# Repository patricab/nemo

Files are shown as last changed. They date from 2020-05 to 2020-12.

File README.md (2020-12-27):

# Nemo - Template board for Atmega328P Microcontroller

This is a template project for a sufrace mounted board, for use with the Atmega328P TQFP package.

What's included:
- Full KiCAD project
- Bill of Materials (BOM)
- Schematic PDF Export

# Full KiCAD project
I have included all project files for use with the open source CAD software KiCAD.
This includes the schematic file, component libraries, netlist and PCB-files

# Schematic PDF Export
Included is a PDF export of the schematic file:

Schematic

# Bill of Materials (BOM)
I have also added a full bill of materials (minus the header-pins), which are sourced from [LCSC](LCSC.com).

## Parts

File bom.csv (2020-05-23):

Reference | Value | Footprint | Datasheet | Price (USD) | LCSC Part #
J5 | Conn_02x03_Odd_Even | Connector_PinHeader_1.27mm:PinHeader_2x03_P1.27mm_Vertical | ~
C5 | 0.33uF | Capacitor_SMD:C_0603_1608Metric_Pad1.05x0.95mm_HandSolder | ~ | 0.015829 | C507077
C6, C2 | 0.1uF | Capacitor_SMD:C_0603_1608Metric_Pad1.05x0.95mm_HandSolder | ~ | 0.015126 | C282518
Y1 | 16MHz | Crystal:Crystal_SMD_3225-4Pin_3.2x2.5mm_HandSoldering | ~ | 0.504318 | C387370
C3 | 18pF | Capacitor_SMD:C_0603_1608Metric_Pad1.05x0.95mm_HandSolder | ~ | 0.0169 | C415402
C4 | 22pF | Capacitor_SMD:C_0603_1608Metric_Pad1.05x0.95mm_HandSolder | ~ | 0.003915 | C376775
C1 | 10uF | Capacitor_SMD:C_0603_1608Metric_Pad1.05x0.95mm_HandSolder | ~ | 0.053491 | C91606
D1 | 1N4001 | Diode_THT:D_DO-41_SOD81_P10.16mm_Horizontal | http://www.vishay.com/docs/88503/1n4001.pdf | 0.019891 | C331627
J3 | Conn_01x02_Male | Connector_PinHeader_1.27mm:PinHeader_1x02_P1.27mm_Vertical | ~
R2 | 1k | Resistor_SMD:R_0603_1608Metric_Pad1.05x0.95mm_HandSolder | ~ | 0.002629 | C328340
D2 | LED | LED_SMD:LED_0603_1608Metric_Pad1.05x0.95mm_HandSolder | ~ | 0.028633 | C434428
SW1 | SW_Push | Button_Switch_SMD:SW_Push_1P1T_NO_CK_KSC7xxJ | ~
J6 | Conn_01x12_Male | Connector_PinHeader_1.27mm:PinHeader_1x12_P1.27mm_Vertical | ~
U1 | ATmega328P-AU | Package_QFP:TQFP-32_7x7mm_P0.8mm | http://ww1.microchip.com/downloads/en/DeviceDoc/ATmega328_P%20AVR%20MCU%20with%20picoPower%20Technology%20Data%20Sheet%2040001984A.pdf | 2.072955 | C14877
J4 | Conn_01x06_Male | Connector_PinHeader_1.27mm:PinHeader_1x06_P1.27mm_Vertical | ~
J2 | Conn_01x06_Male | Connector_PinHeader_1.27mm:PinHeader_1x06_P1.27mm_Vertical | ~
J1 | Conn_01x02_Male | Connector_PinHeader_1.27mm:PinHeader_1x02_P1.27mm_Vertical | ~
R1 | 10k | Resistor_SMD:R_0603_1608Metric_Pad1.05x0.95mm_HandSolder | ~ | 0.000908 | C81087
U2 | L7805 | Package_TO_SOT_SMD:TO-263-2 | http://www.st.com/content/ccc/resource/technical/document/datasheet/41/4f/b3/b0/12/d4/47/88/CD00000444.pdf/files/CD00000444.pdf/jcr:content/translations/en.CD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 | 0.375455 | C53236
 |  |  | Total (USD) | 3.11005
 |  |  | Total (NOK) | 31.1005
 |  |  | +moms | 38.875625

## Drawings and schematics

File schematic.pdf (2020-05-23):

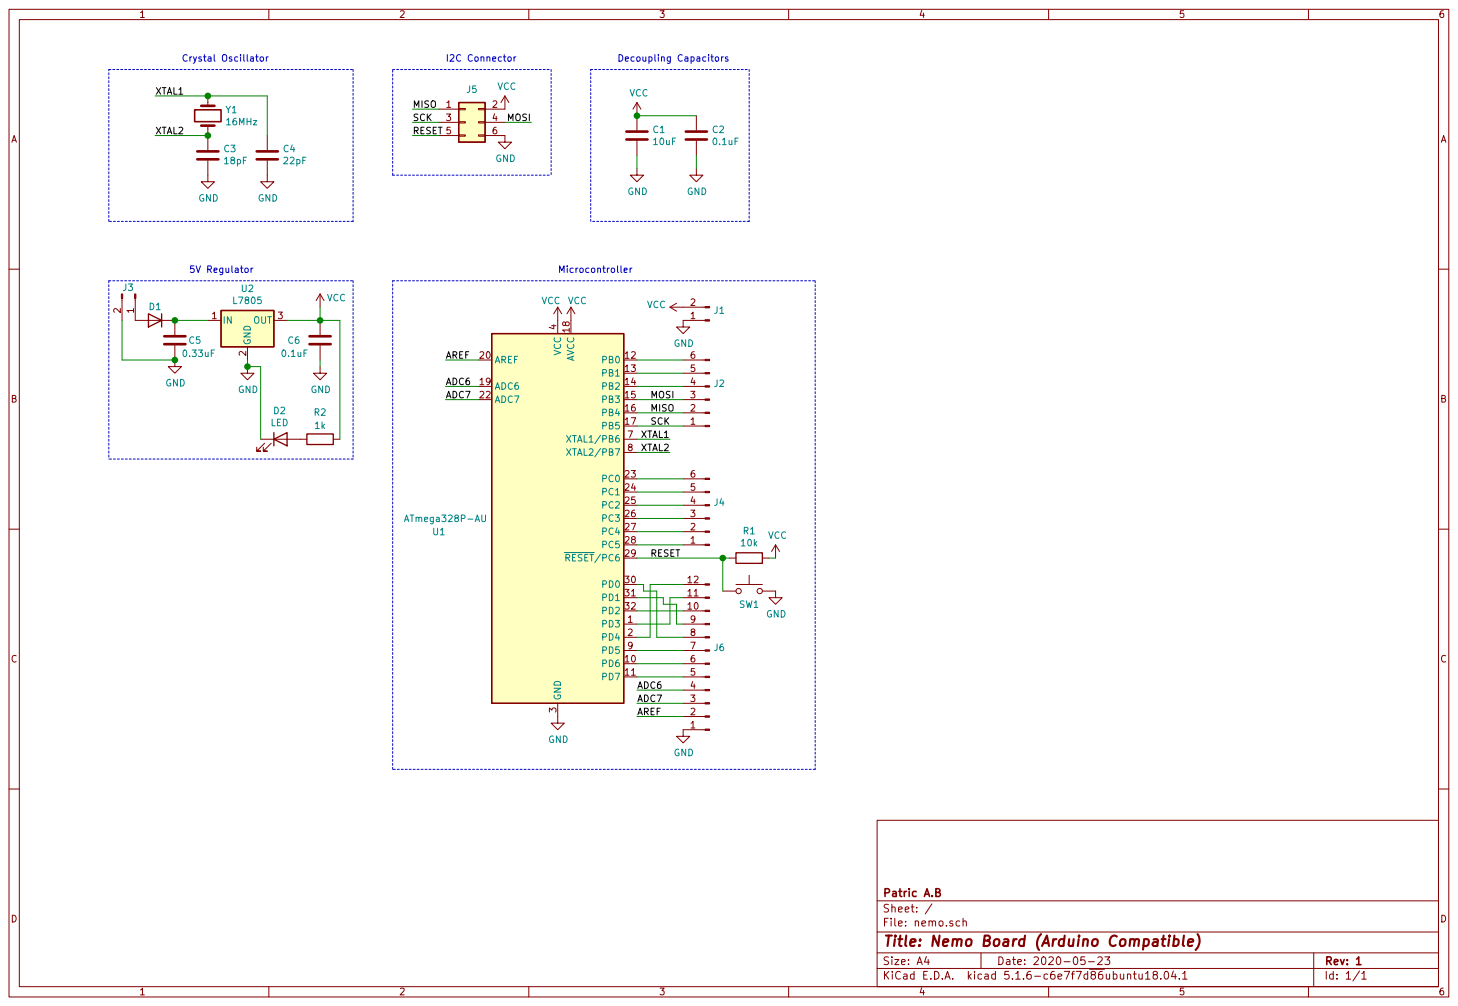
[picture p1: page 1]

Id: 1/1 Title: Nemo Board (Arduino Compatible) File: nemo.sch Sheet: / Patric A.B

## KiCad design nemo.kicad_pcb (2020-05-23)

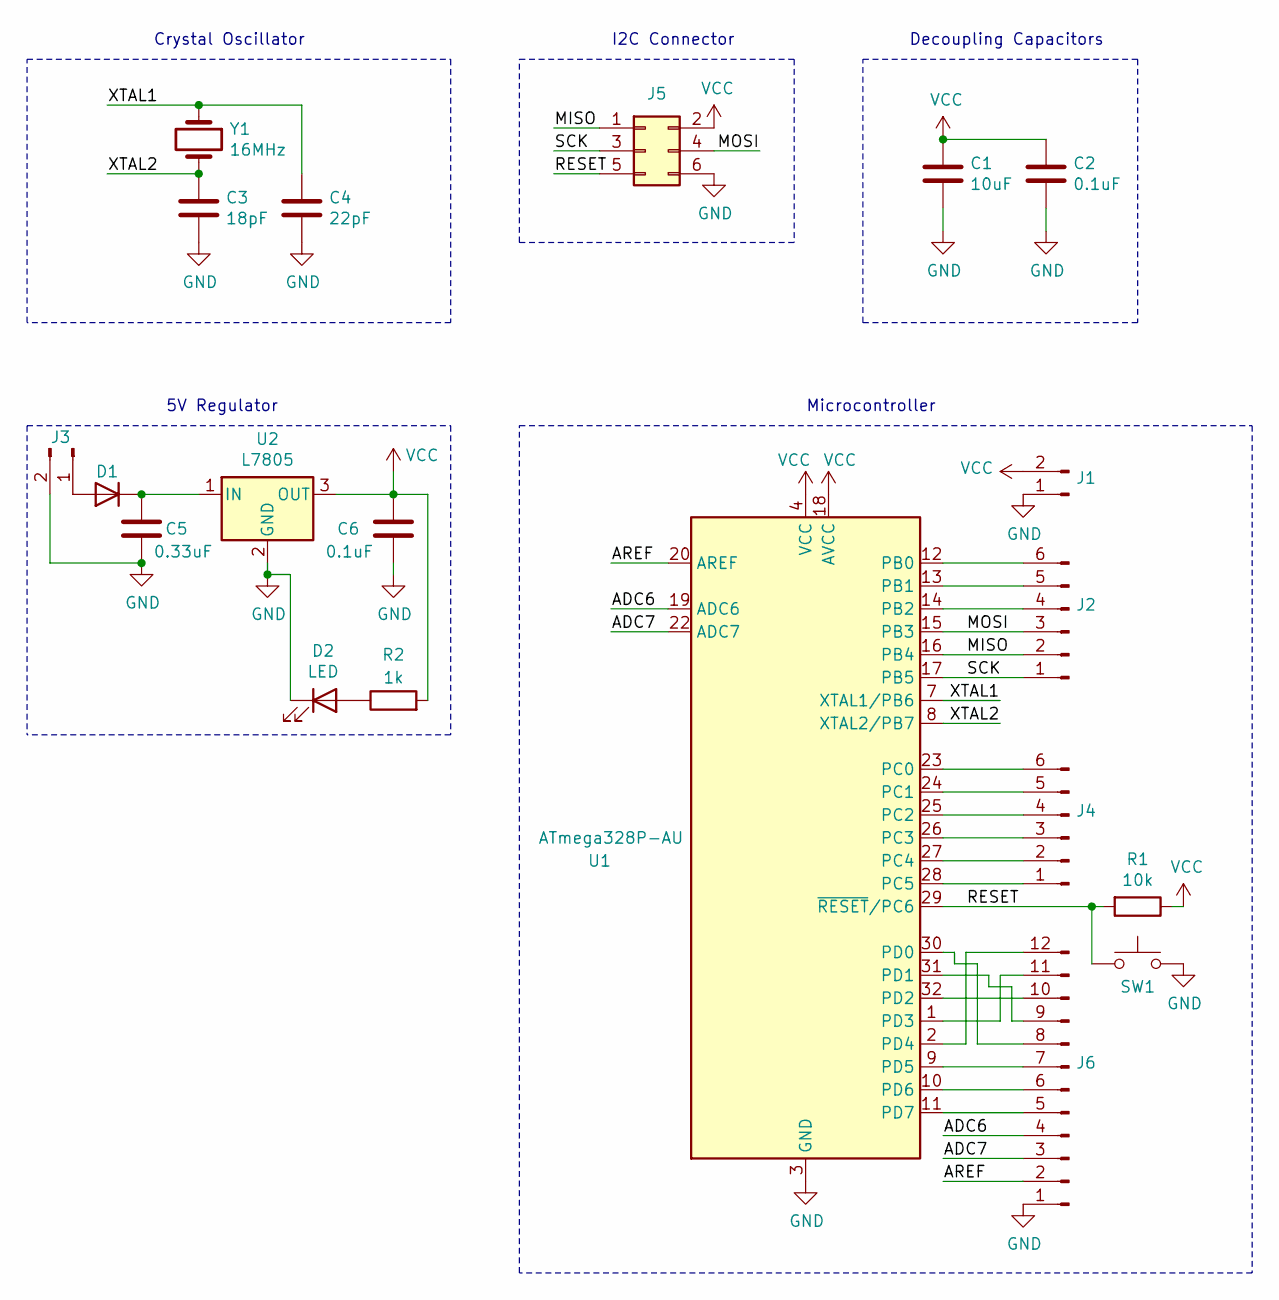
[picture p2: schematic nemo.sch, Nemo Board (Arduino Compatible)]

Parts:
C1: 10uF; C_0603_1608Metric_Pad1.05x0.95mm_HandSolder
C2, C6: 0.1uF; C_0603_1608Metric_Pad1.05x0.95mm_HandSolder
C3: 18pF; C_0603_1608Metric_Pad1.05x0.95mm_HandSolder
C4: 22pF; C_0603_1608Metric_Pad1.05x0.95mm_HandSolder
C5: 0.33uF; C_0603_1608Metric_Pad1.05x0.95mm_HandSolder
D1: 1N4001; D_DO-41_SOD81_P10.16mm_Horizontal
D2: LED; LED_0603_1608Metric_Pad1.05x0.95mm_HandSolder
J1, J3: Conn_01x02_Male; PinHeader_1x02_P1.27mm_Vertical
J2, J4: Conn_01x06_Male; PinHeader_1x06_P1.27mm_Vertical
J5: Conn_02x03_Odd_Even; PinHeader_2x03_P1.27mm_Vertical
J6: Conn_01x12_Male; PinHeader_1x12_P1.27mm_Vertical
R1: 10k; R_0603_1608Metric_Pad1.05x0.95mm_HandSolder
R2: 1k; R_0603_1608Metric_Pad1.05x0.95mm_HandSolder
SW1: SW_Push; SW_Push_1P1T_NO_CK_KSC7xxJ
U1: ATmega328P-AU; TQFP-32_7x7mm_P0.8mm
U2: L7805; TO-263-2
Y1: 16MHz; Crystal_SMD_3225-4Pin_3.2x2.5mm_HandSoldering

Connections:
/ADC6: J6.4, U1.19 (ADC6)
/ADC7: J6.3, U1.22 (ADC7)
/AREF: J6.2, U1.20 (AREF)
/MISO: J2.2, J5.1, U1.16 (PB4)
/MOSI: J2.3, J5.4, U1.15 (PB3)
/RESET: J5.5, R1.2, SW1.1, U1.29 (~RESET~/PC6)
/SCK: J2.1, J5.3, U1.17 (PB5)
/XTAL1: C4.2, U1.7 (XTAL1/PB6), Y1.1
/XTAL2: C3.2, U1.8 (XTAL2/PB7), Y1.2
GND: C1.2, C2.2, C3.1, C4.1, C5.2, C6.2, D2.1 (K), J1.1, J3.2, J5.6, J6.1, SW1.2, U1.3 (GND), U1.5 (GND), U1.21 (GND), U2.2 (GND)
unnamed: C5.1, D1.1 (K), U2.1 (IN)
unnamed: D1.2 (A), J3.1
unnamed: D2.2 (A), R2.1
unnamed: J2.4, U1.14 (PB2)
unnamed: J2.5, U1.13 (PB1)
unnamed: J2.6, U1.12 (PB0)
unnamed: J4.1, U1.28 (PC5)
unnamed: J4.2, U1.27 (PC4)
unnamed: J4.3, U1.26 (PC3)
unnamed: J4.4, U1.25 (PC2)
unnamed: J4.5, U1.24 (PC1)
unnamed: J4.6, U1.23 (PC0)
unnamed: J6.5, U1.11 (PD7)
unnamed: J6.6, U1.10 (PD6)
unnamed: J6.7, U1.9 (PD5)
unnamed: J6.8, U1.30 (PD0)
unnamed: J6.9, U1.31 (PD1)
unnamed: J6.10, U1.32 (PD2)
unnamed: J6.11, U1.1 (PD3)
unnamed: J6.12, U1.2 (PD4)
VCC: C1.1, C2.1, C6.1, J1.2, J5.2, R1.1, R2.2, U1.4 (VCC), U1.6 (VCC), U1.18 (AVCC), U2.3 (OUT)

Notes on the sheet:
5V Regulator
Crystal Oscillator
Decoupling Capacitors
I2C Connector
Microcontroller

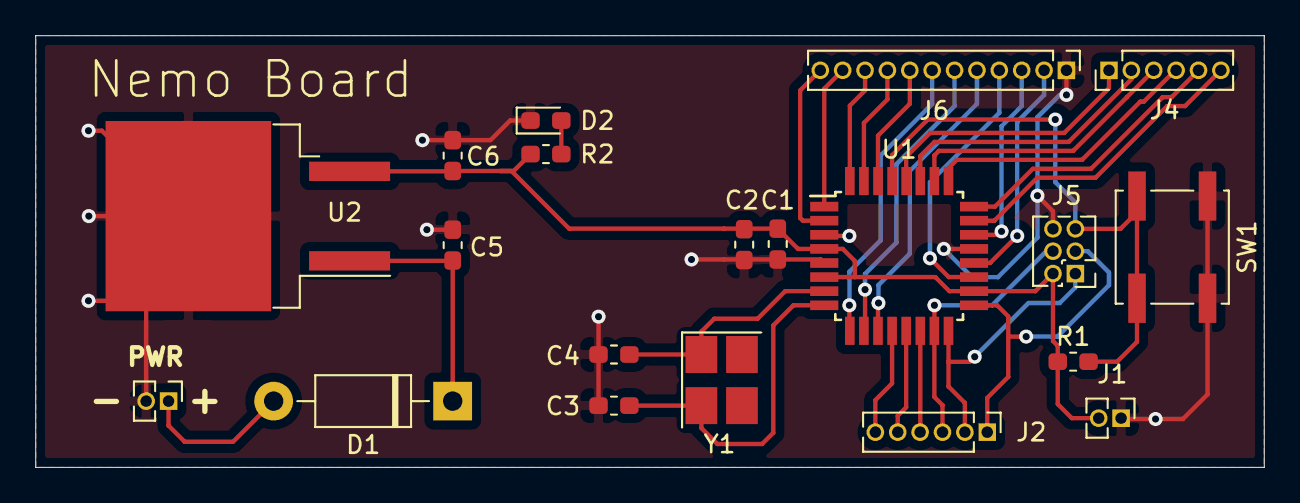
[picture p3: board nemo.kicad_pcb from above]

Board: 2 copper layers, 69.7 x 24.5 mm, 20 parts (0 on the bottom side), 31 nets.

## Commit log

2020-05-22 Initial commit!
    [5v_reg.sch, nemo.kicad_pcb, nemo.sch]
2020-05-23 * Added README.md * Added BOM - bom.csv * Exportet schematic to pdf - schematic.pdf
    [bom.csv, nemo.kicad_pcb, nemo.sch]
2020-06-07 * Improved image display for schematic
